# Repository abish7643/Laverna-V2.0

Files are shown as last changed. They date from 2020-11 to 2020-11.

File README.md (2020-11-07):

# Laverna V2 | Line Follower Robot | 3i INC

This project is a follow up of a previous project, [Laverna](https://github.com/abish7643/Laverna). Compared to the previous one, we used a custom 3D printed chassis (Fork of Brandon Makridis's [design](https://www.thingiverse.com/thing:1584316)), invested more into ligher materials & moved to an Arduino Nano for decreasing size and implementing on a breadboard for better modularity.

All turns are independently handled. That means PID is turned off at turns and Laverna uses a simple way of tackling Acute, Obtuse and Right angles.

> We secured a place in top 3 positions for 6 out of
the 8 participated line follower competitions conducted across different colleges in Kerala during 2019-20. Notables ones are NIT Calicut (Tathva 19), College of Engineering Trivandrum (Escape 19) & CDAC (Techfiesta 2K20).

## Images

Laverna - The Goddess Of Death

Laverna - The Goddess Of Death

## Prerequisites

1. [Qtrsensor 4.0.0 Library](https://github.com/pololu/qtr-sensors-arduino)
2. [Button](https://www.arduinolibraries.info/libraries/button)

All Libraries are included in the repository, upgrade after trying out the included one.

## Components we used

1. [Polulu QTR-8RC Reflectance Sensor](https://www.pololu.com/product/961)
2. [6V 300RPM Micro Gear Motors](https://robu.in/product/n20-6v-300-rpm-micro-metal-gear-motor/) and [Wheel (x2)](https://robokits.co.in/robot-parts/robot-wheels/rubber-wheels/d-axis-43mm-tracking-rubber-wheel-for-n20-dc-geared-motor)
3. [Polulu Castor Wheel](https://robokits.co.in/robot-parts/castors/3pi-n20-universal-ball-wheel-castor) & [Motor Mounting Brackets](https://robokits.co.in/motors/mounting-clamps/n20-metal-gear-micro-dc-motor-mounting-bracket?cPath=2_592_521&)
4. [L293D Motor Driver - IC Only](https://www.electronicscomp.com/l293d-dual-h-bridge-motor-driver-ic)
5. Printed a Custom Chassis (ABS Plastic - White)
   - [Chassis Source](https://www.thingiverse.com/thing:1584316) (Changed The Design To Accomodate Our Components)
   - [A3DXYZ India](https://a3dxyz.com/) (Printing Costed Approximately 450 INR)
6. Arduino Nano (Select any arduino board with sufficient pins)
7. [LIPO 7.4V 850 mAh](https://robokits.co.in/batteries-chargers/skycell-lipo-battery/7.4v-lipo-batteries-2-cell/lithium-polymer-lipo-rechargeable-battery-7.4v-850mah-25c)
8.  One [Button Switch](https://robu.in/product/12x12x7-3mm-tactile-push-button-switch-round/) and One [Power Switch](https://robu.in/product/spst-rocker-switch-pack-of-3/)

## Authors

Abish Vijayan (https://github.com/abish7643/ | abishvijayan7643@gmail.com)

### Contributers

- Abhijit M (abhimadhu523@gmail.com)
- Adith GM (adithgm14@gmail.com)
- Kaveri TS (tscauvery007@gmail.com)

### License

This project is Open Source, Feel free to do whatever you want & also contact any of us if you have any queries.

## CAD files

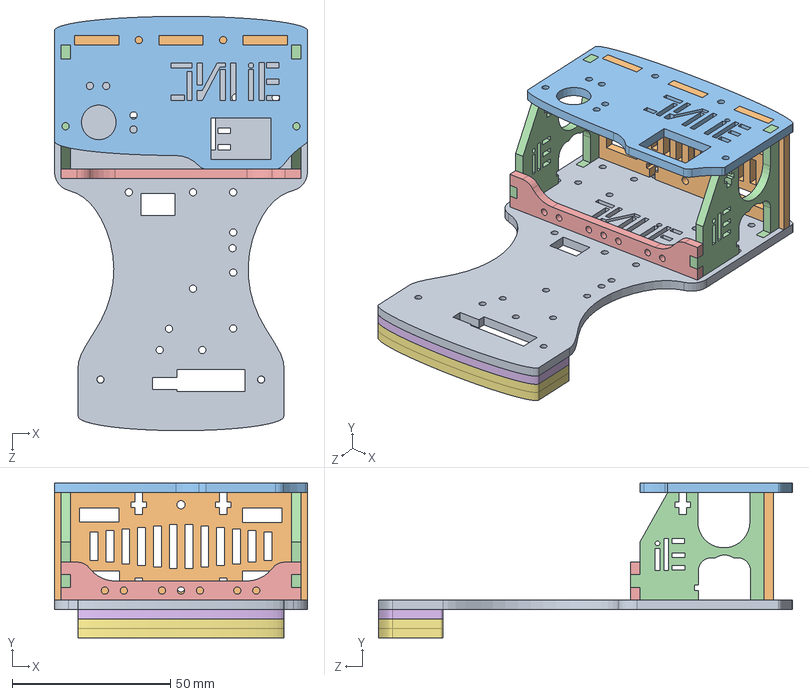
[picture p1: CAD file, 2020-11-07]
Chassis/Chassis/bare-chassis.SLDASM
80.0 x 49.0 x 131.0 mm
chariot-base
chariot-back-wall
chariot-top
chariot-side-walls x 2
chariot-front-wall
chariot-led-shroud
chariot-led-shroud2 x 2

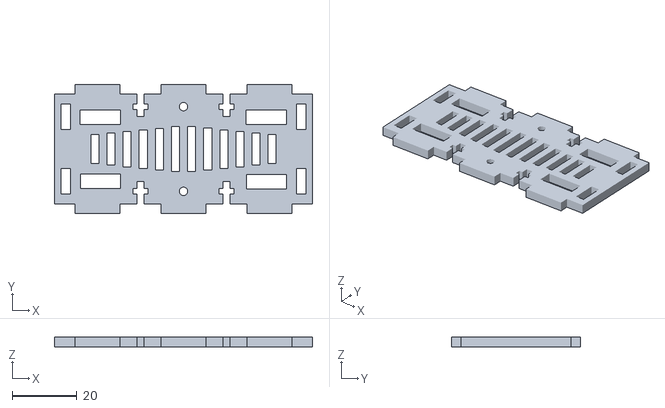
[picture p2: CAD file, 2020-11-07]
Chassis/Chassis STLFile/bare-chassis - chariot-back-wall-1.STL
80.0 x 40.0 x 3.00

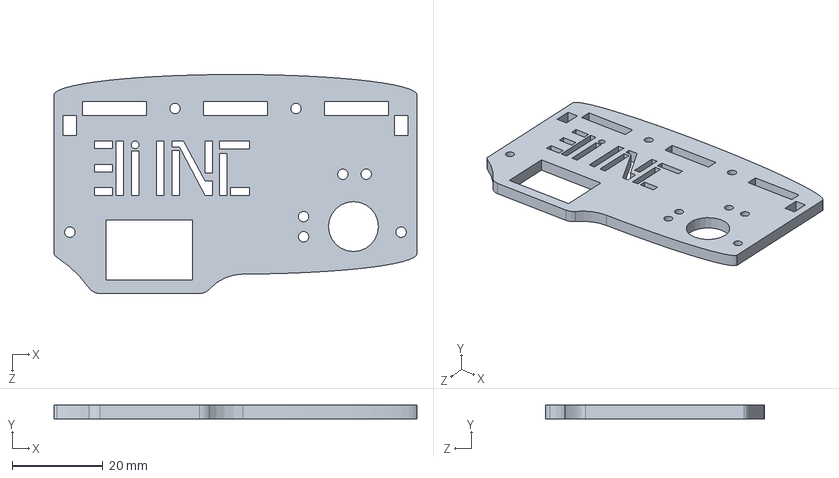
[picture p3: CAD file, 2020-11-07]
Chassis/Chassis/chariot-top.SLDPRT
80.0 x 3.00 x 48.3 mm

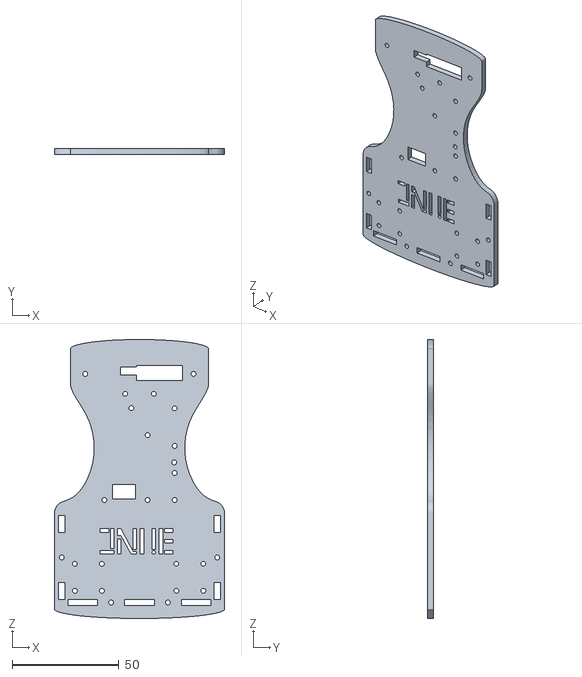
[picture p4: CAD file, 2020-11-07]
Chassis/Chassis STLFile/bare-chassis - chariot-base-1.STL
80.0 x 3.00 x 131.0

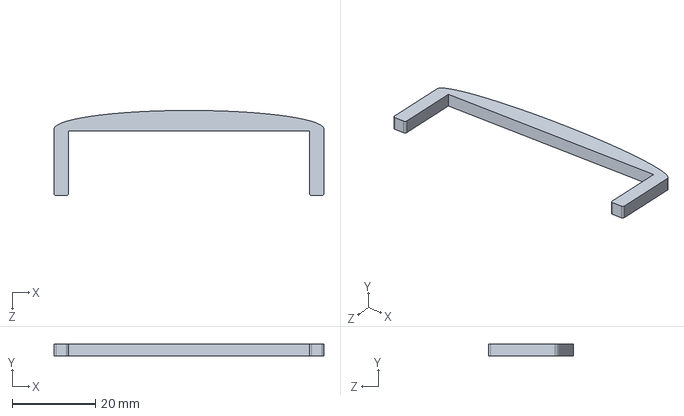
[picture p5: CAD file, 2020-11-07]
Chassis/Chassis/chariot-led-shroud2.SLDPRT
65.0 x 3.00 x 20.5 mm

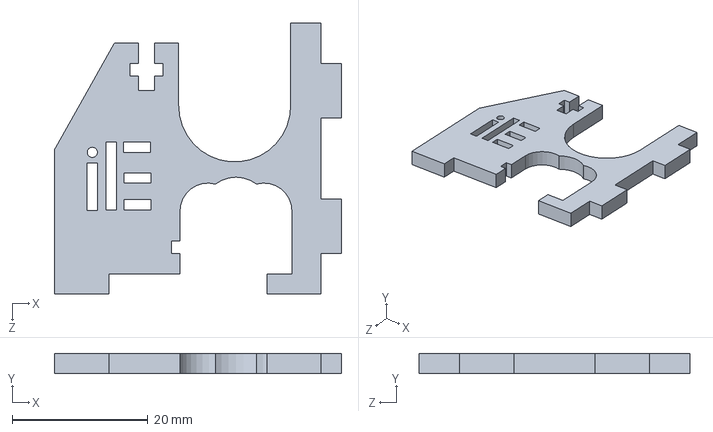
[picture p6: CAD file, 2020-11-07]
Chassis/Chassis/chariot-side-walls.SLDPRT
42.3 x 3.00 x 40.0 mm

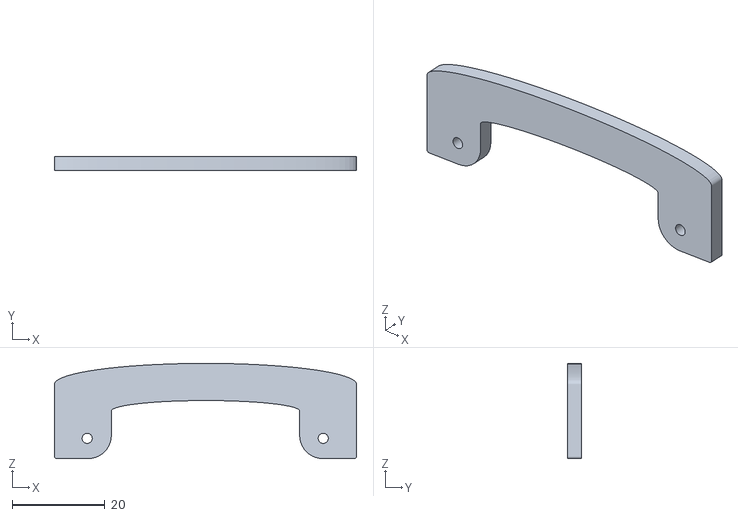
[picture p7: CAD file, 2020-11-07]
Chassis/Chassis STLFile/bare-chassis - chariot-led-shroud-1.STL
65.0 x 3.00 x 20.5

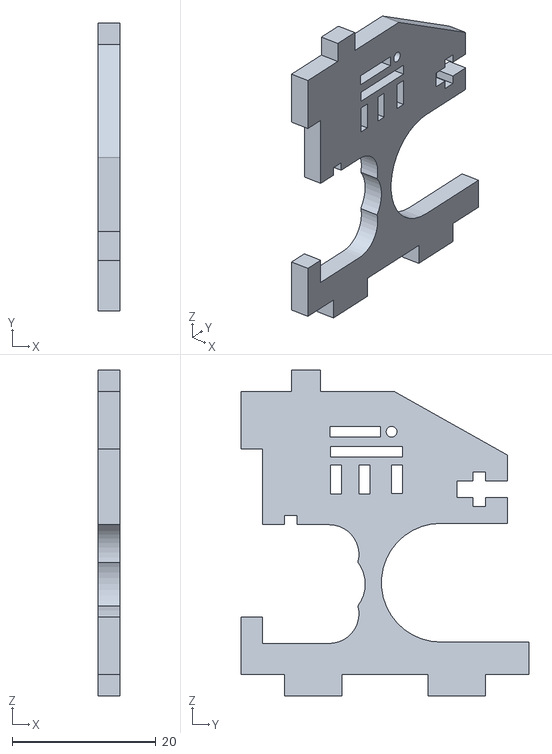
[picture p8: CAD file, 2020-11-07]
Chassis/Chassis STLFile/bare-chassis - chariot-side-walls-1.STL
3.00 x 40.0 x 45.3

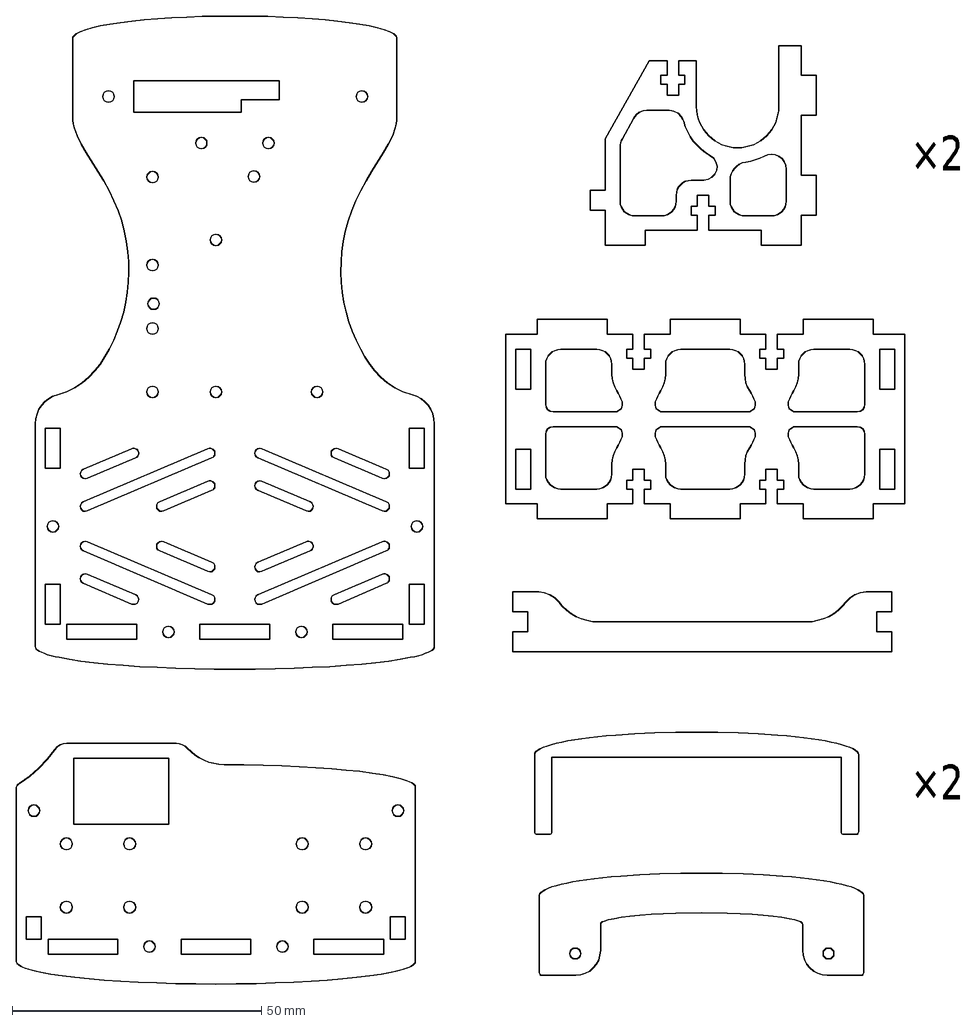
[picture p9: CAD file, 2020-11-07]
Chassis/Chassis/the-chariot.DXF
×2

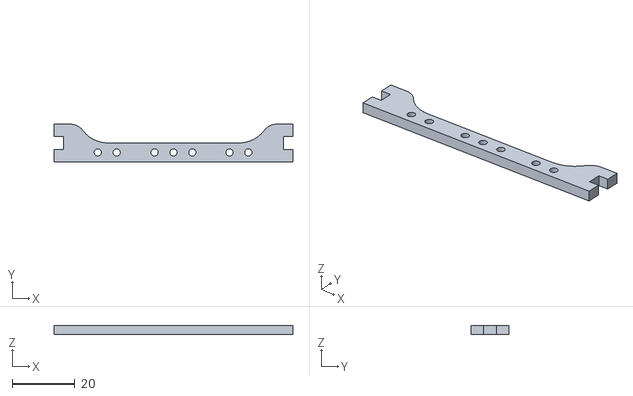
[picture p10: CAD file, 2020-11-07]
Chassis/Chassis STLFile/bare-chassis - chariot-front-wall-1.STL
76.0 x 12.0 x 3.00

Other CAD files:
Chassis/bare-chassis.STEP
Chassis/Chassis STLFile/bare-chassis - chariot-led-shroud2-2.STL
Chassis/Chassis STLFile/bare-chassis - chariot-top-1.STL
Chassis/Chassis/chariot-base.SLDPRT
Chassis/Chassis/chariot-back-wall.SLDPRT
Chassis/Chassis STLFile/bare-chassis - chariot-side-walls-2.STL
Chassis/Chassis/chariot-led-shroud.SLDPRT
Chassis/Chassis/chariot-front-wall.SLDPRT
Chassis/Chassis STLFile/bare-chassis - chariot-led-shroud2-1.STL

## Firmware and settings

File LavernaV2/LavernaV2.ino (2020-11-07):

#include <Button.h>
#include <QTRSensors.h>
#include <Wire.h>

Button button = Button(13, BUTTON_PULLUP_INTERNAL);

QTRSensors qtrrc;
QTRSensors qtrEnd;
const uint8_t SensorCount = 6;
uint16_t sensorValues[SensorCount];
const uint8_t EndSensorCount = 2;
uint16_t endsensorValues[EndSensorCount];

int numberWhiteSensors;

//#define LeftMostSensor 2
//#define RightMostSensor 9

int pinButton = 13; 
int inA1 = A0;
int inA2 = A1;
int inB1  = A2;
int inB2 = A3;
int ENa = 10;
int ENb =11;

int last_proportional = 0;
int integral;
int readPIDConstants = 0;

int blackLine = 1;
//int whiteLine = 0;

//Black Line
float Kp = 0.1;
float Kd = 0.5;
float Ki = 1/10000;
const int max = 80;
unsigned int position;

/*
//White Line
float Kp = 5.50;
float Kd = 9.45;
float Ki = 1/10000;
*/
//#define Kp 7
//#define Kd 3
//#define Ki 1/10000
#define analogKp A7
#define analogKd A6
#define statusLED 12
#define invertionstatusLED A5

void setup(){
  //Serial.begin(9600);
  qtrrc.setTypeRC();
  qtrrc.setSensorPins((const uint8_t[]){3, 4, 5, 6, 7, 8}, SensorCount);
  qtrEnd.setTypeRC();
  qtrrc.setDimmingLevel(31);
  qtrEnd.setSensorPins((const uint8_t[]){2, 9}, EndSensorCount);
  //qtrrc.setEmitterPin(A5); //LEDON Pin - 22
  
  while(button.isPressed()){
    digitalWrite(statusLED, HIGH);
  }
  digitalWrite(statusLED, LOW);
  //Serial.println("Calibrating");   
  
  unsigned int i;
  for(i=0; i<150; i++){
    qtrrc.calibrate();
    delay(10); 
  }
  set_motors(0,0);
  //Serial.println("Calibrated");
  delay(500);
  
  
}


void loop(){
  while(button.isPressed()){
    digitalWrite(statusLED, HIGH);
  }
    delay(500);
    //checkPIDValues(readPIDConstants);
    
  while(1){
    digitalWrite(statusLED, LOW);
    qtrEnd.read(endsensorValues);
    /*
    for (int i=0; i<6; i++){
      Serial.print(sensorValues[i]);
      Serial.print(' ');
      }
    Serial.println(' ');
    */
    /*unsigned int positionSharp = qtrEnd.readLineBlack(endsensorValues);
    for (int i=0; i<2; i++){
      Serial.print(endsensorValues[i]);
      Serial.print(' ');
      }
    Serial.println(' ');
    */
    //checkInversion(endsensorValues, sensorValues);
    putLineState(blackLine);
    turnHandlerWithoutPID(endsensorValues, sensorValues, position);
    //turnHandlerWithoutPIDWhiteLine(endsensorValues, sensorValues, position);
    //Serial.println(numberWhiteSensors);
    /*
    if (blackLine == 1){
      //checkAcuteBlackLine(position, endsensorValues);
      if (position == 0){
      set_motors(-70, 70);
      delay(20);
      }
      if (position == 5000){
      set_motors(70, -70);
      delay(20);
      }
    }
    if (blackLine == 0){
      //checkAcuteWhiteLine(position, endsensorValues);
      if (position == 0){
        set_motors(-80, 80);
        delay(20);
        }
  
      if (position == 5000){
        set_motors(80, -80);
        delay(20);
        }
    }
    */
      
    int proportional = (int(position)) - 2500;
    //Serial.println(position);
    int derivative = proportional - last_proportional;
    integral += proportional;
    int power_difference = Kp * (proportional) + Kd * (derivative) + Ki * (integral);
    last_proportional = proportional;
    
    //Black Line
    //int power_difference = proportional*1.4 + derivative*3 + integral/10000; // + derivative*200;    
    //White Line
    //int power_difference = proportional*7 + derivative*8 + integral/10000;
    
    
    
    //fastNinety(position);
    //checkAcuteWithCount(position);
    //checkAcuteWithEndSensors(position, endsensorValues);
    //Serial.println(power_difference);  
    if(power_difference > max)
      power_difference = max;
    if(power_difference < -max)
      power_difference = -max;
    if(power_difference < 0)
      set_motors(max+power_difference, max);
    else
      set_motors(max, max-power_difference);
  }
}

void set_motors(int left_speed, int right_speed){
  if(right_speed >= 0 && left_speed >= 0){
    analogWrite(ENa, right_speed);
    analogWrite(ENb, left_speed);
    digitalWrite(inA1, HIGH);
    digitalWrite(inA2, LOW);
    digitalWrite(inB1, HIGH);
    digitalWrite(inB2, LOW);
    //Serial.println("Straight");    
  }
  if(right_speed >= 0 && left_speed < 0){
    left_speed = -left_speed;
    analogWrite(ENa, right_speed);
    analogWrite(ENb, left_speed);
    digitalWrite(inA1, LOW);
    digitalWrite(inA2, HIGH);
    digitalWrite(inB1, HIGH);
    digitalWrite(inB2, LOW);
    //Serial.println("Left");
  }
  if(right_speed < 0 && left_speed >= 0){
    right_speed = -right_speed;
    analogWrite(ENa, right_speed);
    analogWrite(ENb, left_speed);
    digitalWrite(inA1, HIGH);
    digitalWrite(inA2, LOW);
    digitalWrite(inB1, LOW);
    digitalWrite(inB2, HIGH);
    //Serial.println("Right");
  } 
}


void checkAcute(int positionLine){
  int turnOppositeA = 0;
  if (positionLine == 0) {
      if (turnOppositeA == 0){
        set_motors(-70, 70);
        delay(500);
        if (positionLine == 0){
          turnOppositeA = 1;
          if (positionLine == 0 && turnOppositeA == 1){
            set_motors(70, -70);
            delay(800);
            turnOppositeA == 0;
          }
        }
      }
      //Serial.println("postion 0");
  }
}

void checkAcuteWithCount(int positionLine){
  //int turnOppositeA = 0;
  if (positionLine == 0) {
    int count = 0;
    for (count=0; positionLine = 0; count++){
      set_motors(-70, 70);
      delay(20);
      if (count == 5 && positionLine == 0){
        for (int countOpposite=0; positionLine = 0; countOpposite++){
          set_motors(70, -70);
          delay(20);
          if (countOpposite == 8) {
            break;
            }
          }
        }
      }
    }
  }

void checkAcuteBlackLine(int positionLine, int ValueofEndSensors[2]){
    if (ValueofEndSensors[1] >= 2000 && ValueofEndSensors[0] <= 1000){
      if (positionLine > 2000 && positionLine < 3000) {
          //Serial.println("Acute Right Triggered");
          set_motors(90, -100);
          delay(110);
        }
      }

    if (ValueofEndSensors[0] >= 2000 && ValueofEndSensors[1] <= 1000){
      if (positionLine > 2000 && positionLine < 3000) {
          //Serial.println("Acute Left Triggered");
          set_motors(-100, 90);
          delay(110);   
        }
      }
  }

  
void checkAcuteWhiteLine(int positionLine, int ValueofEndSensors[2]){
    if (ValueofEndSensors[0] >= 2000 && ValueofEndSensors[1] <= 1000){
      if (positionLine > 2000 && positionLine < 3000) {
          //Serial.println("Acute Right Triggered");
          set_motors(90, -90);
          delay(100);
        }
      }

    if (ValueofEndSensors[1] >= 2000 && ValueofEndSensors[0] <= 1000){
      if (positionLine > 2000 && positionLine < 3000) {
          //Serial.println("Acute Left Triggered");
          set_motors(-90, 90);
          delay(100);   
        }
      }
  }

void checkInversion(int endSensors[2], int otherSensors[6]){
  if (endSensors[0] < 1000 && endSensors[1] < 1000){
      if (otherSensors[2] > 500 && otherSensors[3] > 500) {
        blackLine = 1;
        }
    }
    if (endSensors[0] > 1000 && endSensors[1] > 1000){
      if (otherSensors[2] < 500 && otherSensors[3] < 500) {
        blackLine = 0;
        }
    }}

void putLineState(int lineState){
  if (lineState == 1){
      position = qtrrc.readLineBlack(sensorValues);
      digitalWrite(invertionstatusLED, LOW);
      //Serial.println("BlackLine");
    } else {
      position = qtrrc.readLineWhite(sensorValues);
      digitalWrite(invertionstatusLED, HIGH);
      //Serial.println("WhiteLine");
      }
  }

void checkPIDValues(int ReadState){
  if (ReadState == 0){
      const int p = analogRead(analogKp);
      const int d = analogRead(analogKd);
      const float KP = map(p, 0, 1023, 1, 200);
      const float KD = map(d, 0, 1023, 1, 200);
      Kp = KP/20;
      Kd = KD/20;
      //Serial.print("  Kp : ");
      //Serial.print(Kp);
      //Serial.print("  Kd : ");
      //Serial.print(Kd);
      //Serial.println(" ");
      readPIDConstants = 1;
  }
}
int turn; //Left = 1 & Right = 2
int highestValue;
int LeftendSensor;
int RightendSensor;
void turnHandlerWithoutPID(int endSensors[2], int otherSensors[6], int linePosition){
  LeftendSensor = endSensors[0];
  RightendSensor = endSensors[1];
  if (blackLine == 1){
    if (LeftendSensor >= 1200 && RightendSensor <= 1200) {
      turn = 1;
      //digitalWrite(statusLED, HIGH);
      //Serial.println("ReadytoTurnLeft");
      //Serial.print(LeftendSensor);
    }
    if (RightendSensor >= 1200 && LeftendSensor <= 1200) {
      turn = 2;
      //digitalWrite(statusLED, HIGH);
      //Serial.println("ReadytoTurnRight");
      //Serial.print(RightendSensor);
    }
/*    for (int i = 0; i <= 6; i++){
      if (otherSensors[i] < 500){
       numberWhiteSensors++;
      }else{
       numberWhiteSensors = 0;
      }
    }
    if (numberWhiteSensors >= 6){
      numberWhiteSensors = 6;
      }
    //Serial.println(numberWhiteSensors);
    */
    //if (numberWhiteSensors == 6){
    if (otherSensors[0]<500 && otherSensors[1]<500 && otherSensors[2]<500 && otherSensors[3]<500 && otherSensors[4]<500 && otherSensors[5]<500){
      if (turn==1){
        set_motors(-70, 70);
        digitalWrite(statusLED, HIGH);
        delay(25);
        if (endSensors[0] > 1200 || otherSensors[0] > 400){
          turn = 0;
          digitalWrite(statusLED, HIGH);
          //numberWhiteSensors = 0;
        }
        //Serial.println("LeftTurnWithoutPID");
        }
      if (turn==2){
        set_motors(70, -70);
        digitalWrite(statusLED, HIGH);
        delay(25);
        if (endSensors[1] > 1200 || otherSensors[5] > 400){
          turn = 0;
          digitalWrite(statusLED, HIGH);
          //numberWhiteSensors = 0;
        }
        //Serial.println("RightTurnWithoutPID");
        }
      }
      digitalWrite(statusLED, LOW);
    }
  }
void turnHandlerWithoutPIDWhiteLine(int endSensors[2], int otherSensors[6], int linePosition){
  if (blackLine == 0){
    if (LeftendSensor <= 1000 && RightendSensor >= 1000) {
      turn = 1;
      //Serial.println("ReadytoTurnLeft");
      //Serial.print(LeftendSensor);
    }
    if (RightendSensor <= 1000 && LeftendSensor >= 1000) {
      turn = 2;
      //Serial.println("ReadytoTurnRight");
      //Serial.print(RightendSensor);
    }
    for (int i = 0; i <= 6; i++){
      if (otherSensors[i] > 500){
       numberWhiteSensors++;
      }else{
       numberWhiteSensors = 0;
      }
    }
    if (numberWhiteSensors >= 6){
      numberWhiteSensors = 6;
      }
    //Serial.println(numberWhiteSensors);
    if (numberWhiteSensors == 6){
      if (turn==1){
        set_motors(-100, 100);
        delay(20);
        if (endSensors[0] < 1200 || otherSensors[0] < 500){
          turn = 0;
        }
        //Serial.println("LeftTurnWithoutPID");
        }
      if (turn==2){
        set_motors(100, -100);
        delay(20);
        if (endSensors[0] < 1200 || otherSensors[0] < 500){
          turn = 0;
        }
        //Serial.println("RightTurnWithoutPID");
        }
      }
    }
  }

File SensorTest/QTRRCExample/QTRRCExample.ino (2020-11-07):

#include <QTRSensors.h>

// The main loop of the example reads the calibrated sensor values and uses
// them to estimate the position of a line. You can test this by taping a piece
// of 3/4" black electrical tape to a piece of white paper and sliding the
// sensor across it. It prints the sensor values to the serial monitor as
// numbers from 0 (maximum reflectance) to 1000 (minimum reflectance) followed
// by the estimated location of the line as a number from 0 to 5000. 1000 means
// the line is directly under sensor 1, 2000 means directly under sensor 2,
// etc. 0 means the line is directly under sensor 0 or was last seen by sensor
// 0 before being lost. 5000 means the line is directly under sensor 5 or was
// last seen by sensor 5 before being lost.

QTRSensors qtr;

const uint8_t SensorCount = 8;
uint16_t sensorValues[SensorCount];

int contrastValue = 0;

void setup()
{
  // configure the sensors
  qtr.setTypeRC();
  qtr.setSensorPins((const uint8_t[]){2, 3, 4, 5, 6, 7, 8, 9}, SensorCount);
  qtr.setEmitterPin(A5);
  delay(500);
  pinMode(LED_BUILTIN, OUTPUT);
  digitalWrite(LED_BUILTIN, HIGH); // turn on Arduino's LED to indicate we are in calibration mode

  // 2.5 ms RC read timeout (default) * 10 reads per calibrate() call
  // = ~25 ms per calibrate() call.
  // Call calibrate() 400 times to make calibration take about 10 seconds.
  for (uint16_t i = 0; i < 100; i++)
  {
    qtr.calibrate();
  }
  digitalWrite(LED_BUILTIN, LOW); // turn off Arduino's LED to indicate we are through with calibration

  // print the calibration minimum values measured when emitters were on
  Serial.begin(9600);
  for (uint8_t i = 0; i < SensorCount; i++)
  {
    Serial.print(qtr.calibrationOn.minimum[i]);
    Serial.print(' ');
    
  }
  Serial.println();

  // print the calibration maximum values measured when emitters were on
  for (uint8_t i = 0; i < SensorCount; i++)
  {
    Serial.print(qtr.calibrationOn.maximum[i]);
    Serial.print(' ');
  }
  Serial.println();
  Serial.println();
  delay(1000);
}

void loop()
{
  // read calibrated sensor values and obtain a measure of the line position
  // from 0 to 5000 (for a white line, use readLineWhite() instead)
  uint16_t position = qtr.readLineBlack(sensorValues, QTRReadMode::OnAndOff);

  // print the sensor values as numbers from 0 to 1000, where 0 means maximum
  // reflectance and 1000 means minimum reflectance, followed by the line
  // position
  for (uint8_t i = 0; i < SensorCount; i++)
  {
    Serial.print(sensorValues[i]);
    Serial.print('\t');
    contrastValue = contrastValue + sensorValues[i];
    
  }
  Serial.print(contrastValue);
  contrastValue = 0;
  Serial.println('\t');
  Serial.println(position);

  delay(250);
}

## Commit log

2020-03-08 Test Motor && Sensors
2020-03-08 Removed Serial Print, Adjusted End Sensor Threshold Values
2020-03-08 Sensor Test (Comments)
2020-11-07 Added Chassis Design Files, Libraries, Images & Readme
    [bare-chassis - chariot-back-wall-1.STL, bare-chassis - chariot-base-1.STL, bare-chassis - chariot-front-wall-1.STL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]
2020-11-07 Removed Test Motor
